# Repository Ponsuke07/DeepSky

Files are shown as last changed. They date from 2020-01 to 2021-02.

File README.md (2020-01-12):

View this project on [CADLAB.io](https://cadlab.io/project/1893). 

# DeepSky
*DeepSky* is a Open Source JTAG Adapter based on FTDI FT2232.  
*Deepsky* is also designed JTAGKey clone.

# Supported Software
[OpenOCD][1] support ([config file](./conf/openocd/deepsky.cfg)).  

[1]:http://openocd.org/

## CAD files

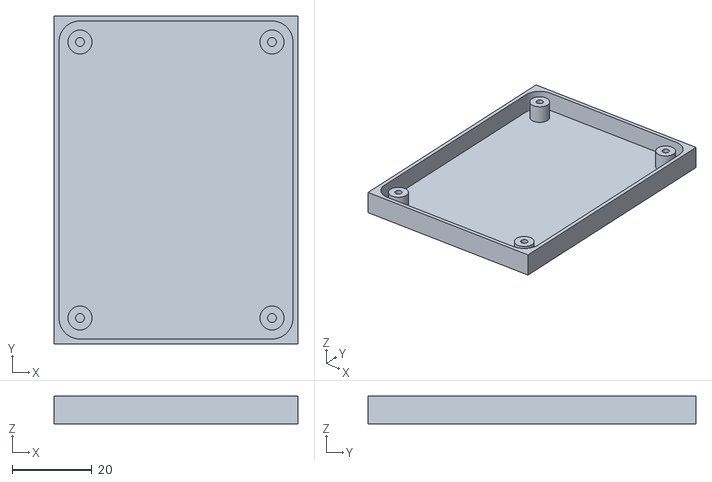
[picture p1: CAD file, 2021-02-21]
case/case_small.stl
61.0 x 82.0 x 7.00

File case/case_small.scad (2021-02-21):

x = 58;
y = 79;
h = 7;

difference(){
translate([0, 0,  h/2-1]) cube([x+3, y+3, h],center=true);

    union(){
        _m=0.5;
        _r=5+(_m/2);
        translate([0, 0, 10/2  ]) cube([x+_m-(_r*2), y+_m, 10],center=true);
        translate([0, 0, 10/2  ]) cube([x+_m, y+_m-(_r*2), 10],center=true);
        translate([ off_x, off_y, 0])cylinder(r=_r,h=10);
        translate([-off_x, off_y, 0])cylinder(r=_r,h=10);
        translate([ off_x,-off_y, 0])cylinder(r=_r,h=10);
        translate([-off_x,-off_y, 0])cylinder(r=_r,h=10);
    }

}

off_x = (x/2-5);
off_y = (y/2-5);
$fn=50;

difference(){
    union(){
        translate([ off_x, off_y, 0])cylinder(r=3,h=h-1.6);
        translate([-off_x, off_y, 0])cylinder(r=3,h=h-1.6);
        translate([ off_x,-off_y, 0])cylinder(r=3,h=h-1.6);
        translate([-off_x,-off_y, 0])cylinder(r=3,h=h-1.6);
    }
    translate([ off_x, off_y, 0])cylinder(r=1.1,h=7);
    translate([-off_x, off_y, 0])cylinder(r=1.1,h=7);
    translate([ off_x,-off_y, 0])cylinder(r=1.1,h=7);
    translate([-off_x,-off_y, 0])cylinder(r=1.1,h=7);
}

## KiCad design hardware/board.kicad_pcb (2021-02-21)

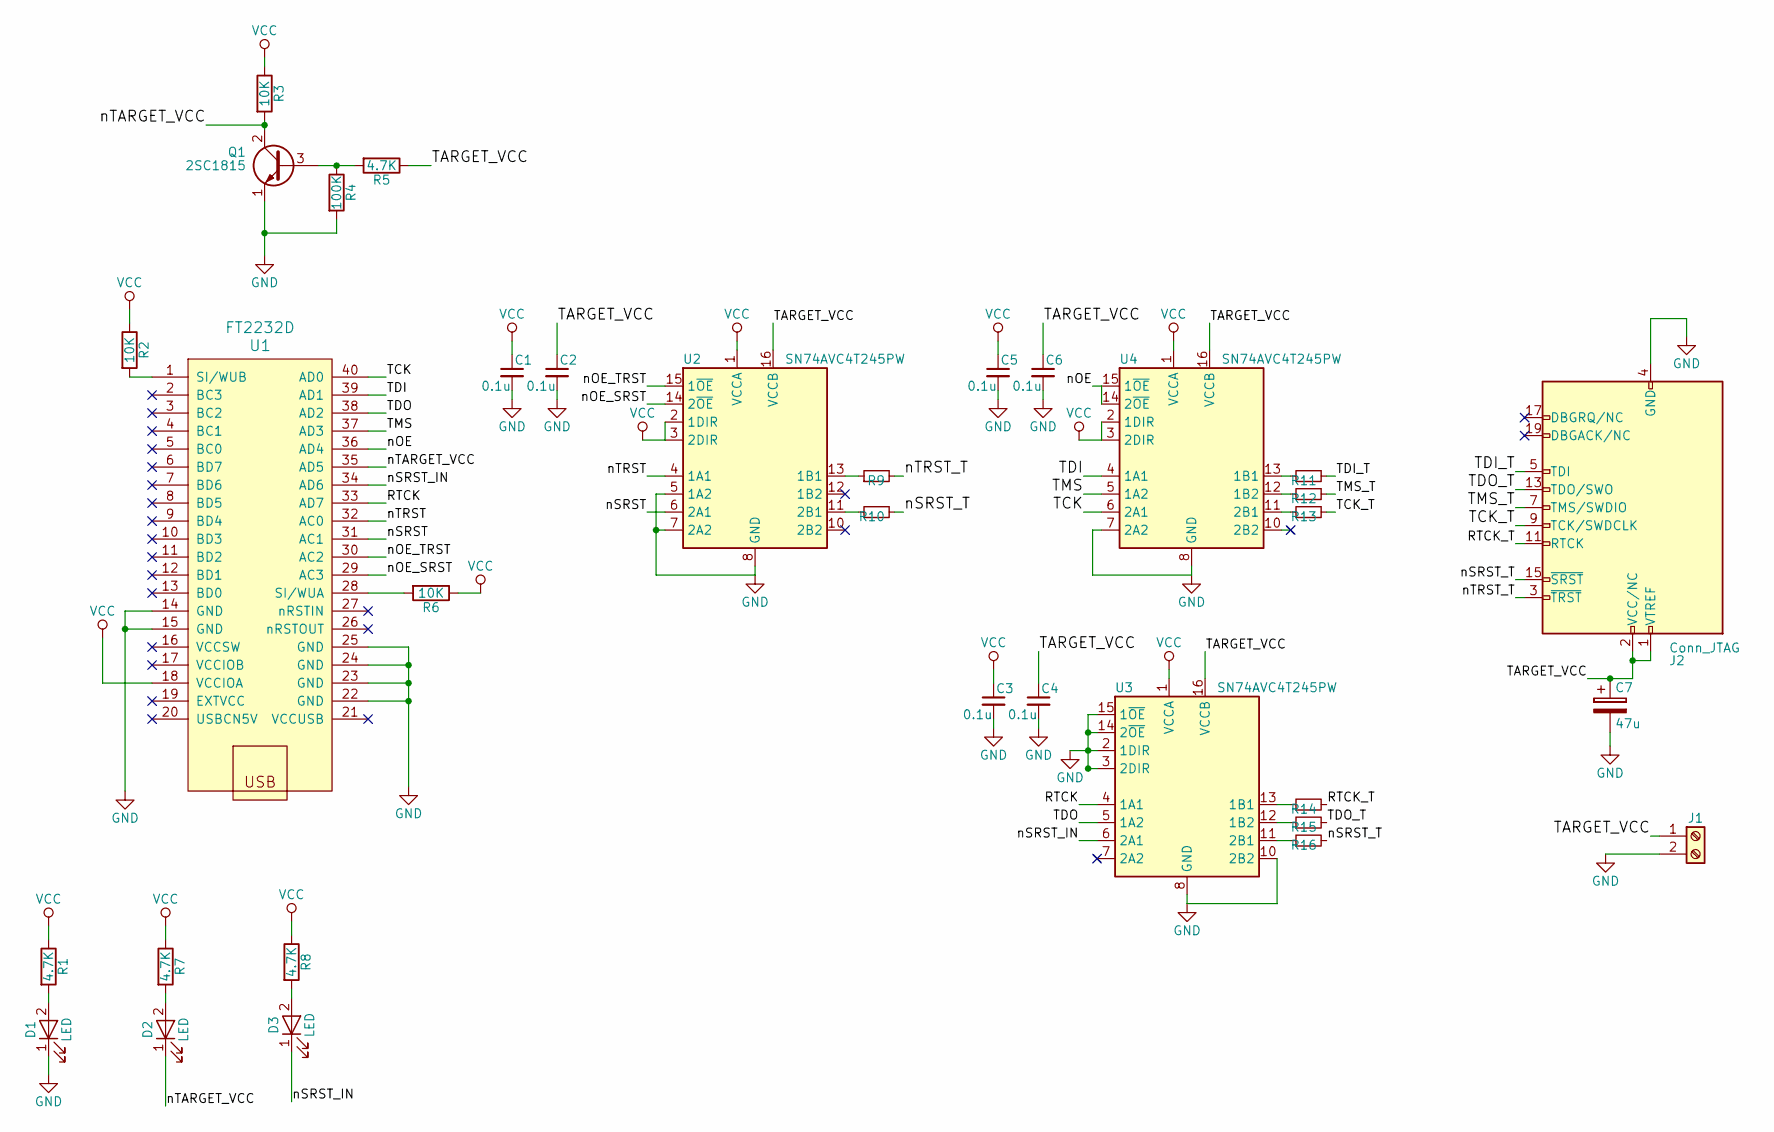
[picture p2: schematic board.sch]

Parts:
C1, C2, C3, C4, C5, C6: 0.1u; C_0805_HandSoldering
C7: 47u; CP_Elec_8x6.7
D1, D2, D3: LED; LED_D3.0mm
J1: Screw_Terminal_01x02; TerminalBlock_Phoenix_MKDS1.5-2pol
J2: Conn_JTAG; Pin_Header_Straight_2x10_Pitch2.54mm
Q1: 2SC1815; TO-92_Inline_Wide
R1, R5, R7, R8: 4.7K; R_0805_HandSoldering
R2, R3, R6: 10K; R_0805_HandSoldering
R4: 100K; R_Axial_DIN0207_L6.3mm_D2.5mm_P10.16mm_Horizontal
R9, R10, R11, R12, R13, R14, R15, R16: 68; R_0805_HandSoldering
U1: FT2232D; AE-FT2232
U2, U3, U4: SN74AVC4T245PW; TSSOP-16_4.4x5mm_P0.65mm

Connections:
/RTCK: U1.33 (AD7), U3.4 (1A1)
/RTCK_T: J2.11 (RTCK), R14.2
/TARGET_VCC: C2.1, C4.1, C6.1, C7.1, J1.1, J2.1 (VTREF), J2.2 (VCC/NC), R5.1, U2.16 (VCCB), U3.16 (VCCB), U4.16 (VCCB)
/TCK: U1.40 (AD0), U4.6 (2A1)
/TCK_T: J2.9 (TCK/SWDCLK), R13.2
/TDI: U1.39 (AD1), U4.4 (1A1)
/TDI_T: J2.5 (TDI), R11.2
/TDO: U1.38 (AD2), U3.5 (1A2)
/TDO_T: J2.13 (TDO/SWO), R15.2
/TMS: U1.37 (AD3), U4.5 (1A2)
/TMS_T: J2.7 (TMS/SWDIO), R12.2
/nOE: U1.36 (AD4), U4.14 (2~OE), U4.15 (1~OE)
/nOE_SRST: U1.29 (AC3), U2.14 (2~OE)
/nOE_TRST: U1.30 (AC2), U2.15 (1~OE)
/nSRST: U1.31 (AC1), U2.6 (2A1)
/nSRST_IN: D3.1 (K), U1.34 (AD6), U3.6 (2A1); also elsewhere on the board
/nSRST_T: J2.15 (~SRST~), R10.2, R16.2
/nTARGET_VCC: D2.1 (K), Q1.2 (C), R3.2, U1.35 (AD5); also elsewhere on the board
/nTRST: U1.32 (AC0), U2.4 (1A1)
/nTRST_T: J2.3 (~TRST~), R9.2
GND: C1.2, C2.2, C3.2, C4.2, C5.2, C6.2, C7.2, D1.1 (K), J1.2, J2.4 (GND), J2.6 (GND), J2.8 (GND), J2.10 (GND), J2.12 (GND), J2.14 (GND), J2.16 (GND), J2.18 (GND), J2.20 (GND), Q1.1 (E), R4.2, U1.14 (GND), U1.15 (GND), U1.22 (GND), U1.23 (GND), U1.24 (GND), U1.25 (GND), U2.5 (1A2), U2.7 (2A2), U2.8 (GND), U2.9 (GND), U3.2 (1DIR), U3.3 (2DIR), U3.8 (GND), U3.9 (GND), U3.10 (2B2), U3.14 (2~OE), U3.15 (1~OE), U4.7 (2A2), U4.8 (GND), U4.9 (GND); also elsewhere on the board
unnamed 21: D1.2 (A), R1.2; also elsewhere on the board
unnamed 22: D2.2 (A), R7.2; also elsewhere on the board
unnamed 23: D3.2 (A), R8.2; also elsewhere on the board
unnamed: Q1.3 (B), R4.1, R5.2
unnamed: R2.2, U1.1 (SI/WUB)
unnamed: R6.2, U1.28 (SI/WUA)
unnamed: R9.1, U2.13 (1B1)
unnamed: R10.1, U2.11 (2B1)
unnamed: R11.1, U4.13 (1B1)
unnamed: R12.1, U4.12 (1B2)
unnamed: R13.1, U4.11 (2B1)
unnamed: R14.1, U3.13 (1B1)
unnamed: R15.1, U3.12 (1B2)
unnamed: R16.1, U3.11 (2B1)
VCC: C1.1, C3.1, C5.1, R1.1, R2.1, R3.1, R6.1, R7.1, R8.1, U1.18 (VCCIOA), U2.1 (VCCA), U2.2 (1DIR), U2.3 (2DIR), U3.1 (VCCA), U4.1 (VCCA), U4.2 (1DIR), U4.3 (2DIR)

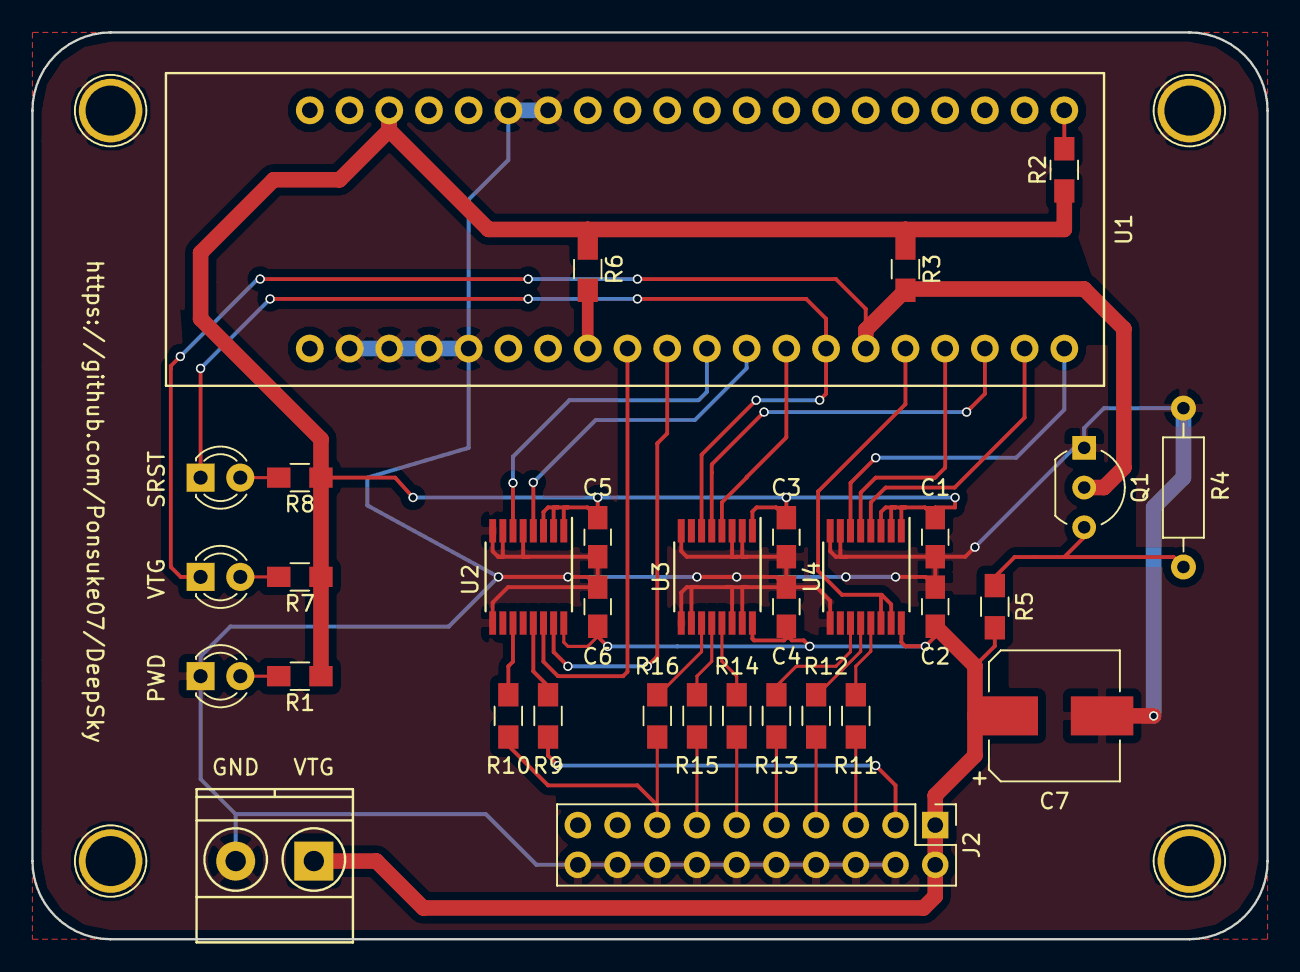
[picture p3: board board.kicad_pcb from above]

Board: 2 copper layers, 79.0 x 58.0 mm, 33 parts (0 on the bottom side), 36 nets.

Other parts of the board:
PWD: LED; LED_D3.0mm
SRST: LED; LED_D3.0mm
VTG: LED; LED_D3.0mm

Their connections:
/nSRST_IN: SRST.1; also elsewhere on the board
/nTARGET_VCC: VTG.1; also elsewhere on the board
GND: PWD.1; also elsewhere on the board
unnamed 21: PWD.2; also elsewhere on the board
unnamed 22: VTG.2; also elsewhere on the board
unnamed 23: SRST.2; also elsewhere on the board

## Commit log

2019-06-21 Add gitignore for kicad
2019-06-22 hardware: Add schematic
    [board.kicad_pcb, board.sch]
2019-06-22 hardware: Add LEDs and register to protect undershoot
    [board.sch]
2019-06-23 hardware: Bump up the version to 0.1
    [board.kicad_pcb, board.sch]
2019-08-28 hardware: Fix connection of LED
    [board.kicad_pcb]
2019-08-28 conf: Add deepsky.cfg for openocd
    [deepsky.cfg]
2021-02-21 case: Add simple small case
    [case_small.scad]
2021-02-21 hardware: Minor update v1.0.1
    [board.kicad_pcb]
2021-02-21 conf: Define default adapter_khz
    Set adapter clock to 15MHz by default.
    [deepsky.cfg]
2021-02-21 case: Update case for pcb v1.0.1
    [case_small.scad, case_small.stl]
